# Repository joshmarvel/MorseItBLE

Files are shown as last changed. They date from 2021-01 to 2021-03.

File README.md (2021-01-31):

# MorseItBLE
A simple Bluetooth interface to use a hardware CW key with the Morse-it app with battery charge indication and reset functionality
### Morse-it Bluetooth Low Emissions Hardware Key
Read more over on my site: [M0WYP.com](https://m0wyp.com/2020/05/08/morse-it-ble-hardware-cw-key/)

### New in Version 2
#### For iOS version 14 or greater only
Get [version 1.0](https://github.com/joshmarvel/MorseItBLE/releases/tag/V1.0) for older iOS versions.

Utilizes iOS 14's ability to repeat a key hold and therefore eliminates the need to send the up arrow.  This should solve a great number of timing issues in the previous version.  However, if you find that there are timing errors (this seems to be related to various types of Apple hardware), make adjustments to the delay lines 76 and 88 in MorseItBLE.ino.

#### This project utilizes (at minimum):

1. An iOS device with Bluetooth LE capabilities
2. [Morse-it](https://apps.apple.com/us/app/morse-it/id284942940)
3. [Adafruit Feather 32u4 Bluefruit LE](https://www.adafruit.com/product/2829)
4. And a physical CW key of your choice.
5. Various bits of wire and a micro USB cable
6. Soldering iron and solder, wire strippers and other basic electronics tools.

#### Procedure
1. Update the firmware on Feather
   1. Easiest way is to download [BlueFruit Connect](https://apps.apple.com/us/app/bluefruit-connect/id830125974)
   2. Open the app, find the "Adafruit Bluefruit LE" device and click the "Connect" button
   3. Scroll down the list, find the "Update" menu option and install the latest firmware
2. Download and install the [Arduino IDE](https://www.arduino.cc/en/main/software)
3. Follow the [Adafruit Arduino setup](https://learn.adafruit.com/adafruit-arduino-ide-setup) guide to add the Adafruit boards to the IDE.
4. Connect the board to the computer with a micro USB cable
5. Create new project in the Arduino IDE
6. Copy the 3 files from the project into your new project.
7. Compile the project
8. Upload the project to the board
9. Wire the CW key to the board
   1. GND - Common on the CW key
   2. PIN A0 - Red LED
   3. PIN A1 - Green LED
   4. PIN A2 - Blue LED
   5. PIN A3 - RESET button
   6. PIN A4 - Dah(_) for iambic keys
   7. PIN A5 - Dit(.) for iambic keys or both for straight keys
10. On your iOS device, go to "Settings" -> "Bluetooth" and discover "MorseKey"
11. Open Morse-it, go the "Tap" tab and test sending.

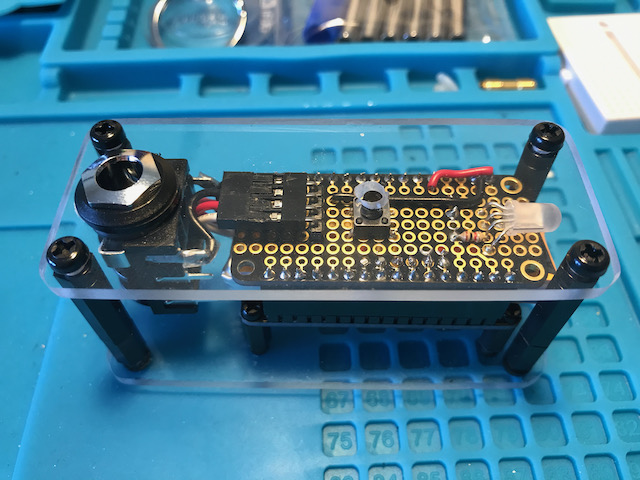
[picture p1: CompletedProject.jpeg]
Completed Project


#### A huge thanks to the work done by Chris Young on his [tutorials](https://learn.adafruit.com/ios-switch-control-using-ble) and [GitHub page](https://github.com/cyborg5/iOS_switch_control/).  This project is adapted and modified from his original work and is licensed under [Creative Commons ShareALike](https://creativecommons.org/licenses/by-nc-sa/4.0/legalcode).

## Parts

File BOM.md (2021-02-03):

# Build of Materials
I've included links to purchase most of the parts at [Adafruit](https://www.adafruit.com/) for ease of purchasing.  Not all parts are as pictured.

| Part | Description | Quantity | Link |
| --- | --- | --- | --- |
| Adafruit Feather 32u4 Bluefruit LE | Main Board | 1 | [Link](https://www.adafruit.com/product/2829) | 
| FeatherWing Proto - Prototyping Add-on For All Feather Boards | Add-on Board | 1 | [Link](https://www.adafruit.com/product/2884) |
| Header Kit for Feather - 12-pin and 16-pin Female Header Set | Headers | 1 | [Link](https://www.adafruit.com/product/2886) |
| Break-away 0.1" 36-pin strip right-angle male header (10 pack) | Headers | 1 | [Link](https://www.adafruit.com/product/1540) | 
| Lithium Ion Polymer Battery Ideal For Feathers - 3.7V 400mAh | Battery | 1 | [Link](https://www.adafruit.com/product/3898) |
| Neutrik NMJ6HCD2 | Switching Jack | 1 | [Link](https://www.neutrik.com/en/product/nmj6hcd2)|
| Diffused RGB (tri-color) LED - Common Anode | LED | 1 | [Link](https://www.adafruit.com/product/159) |
| 4 Pin 2.54mm Dupont Housing | Connector | 1 | [Link](https://www.adafruit.com/product/3145) |
| Female 2.54mm Dupont cable - pre-terminated > 40 mm| Main Board to Jack cable | 4 | [Link](https://www.adafruit.com/product/3141) | 
| 2.0mm JST-PH JST Connector | Power Connector | 1 | [Link](https://www.adafruit.com/product/4422) |
| Through-Hole Resistors - 1.0K ohm 5% 1/4W | Resistor | 1 | [Link](https://www.adafruit.com/product/4294) |
| Tactile Switch Button | Reset Switch | 1 | [Link](https://www.adafruit.com/product/1119) |
| 6 mm Black Nylon Screw - M3 | Case Screws | 8 | [Link](https://www.adafruit.com/product/4685) |
| 30mm Black Nylon Standoff - M3 | Case Standoffs | 4 | [Link](https://www.adafruit.com/product/4685) |
| 6 mm Black Nylon Screw - M2.5 | Main Board Mounting Screws | 8 | [Link](https://www.adafruit.com/product/3299) |
| 10 mm Black Nylon Standoff - M2.5 | Main Board Mounting Standoffs | 4 | [Link](https://www.adafruit.com/product/3299) |
| Misc Multicoloured Silicone Wire | Wire | 1 | [Link](https://www.adafruit.com/product/1970) | 
| 3mm Custom Plexiglass Top Case | Case | 1 | Widely Available |
| 3mm Custom Plexiglass Bottom Case | Case | 1 | Widely Available |

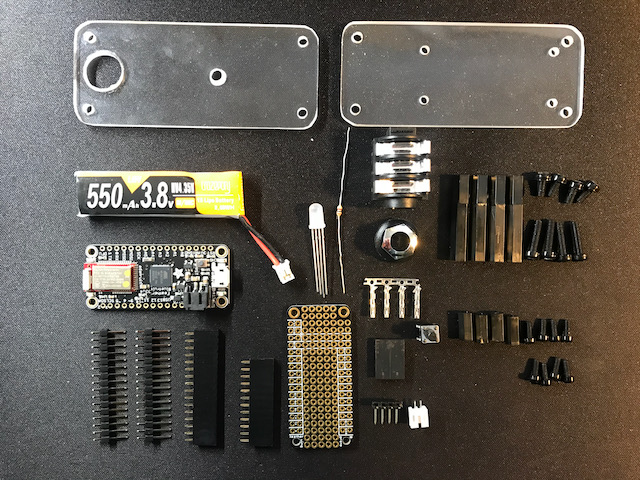
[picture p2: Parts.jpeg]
Part List


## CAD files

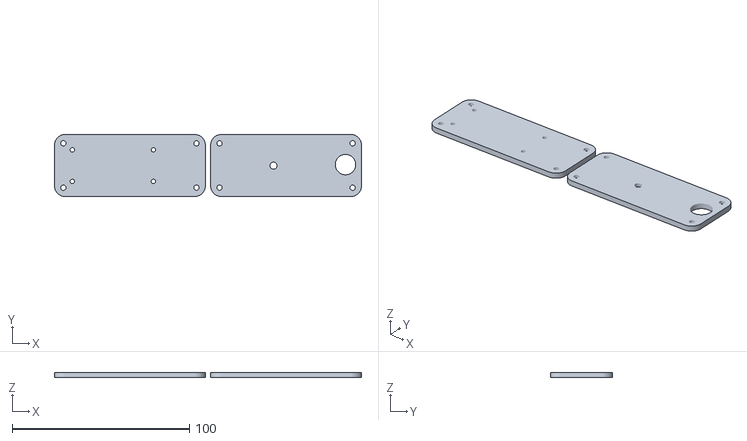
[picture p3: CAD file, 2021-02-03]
MorseItBLE_Case.stl
173.0 x 35.0 x 3.00

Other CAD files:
MorseItBLE_Case.dwg

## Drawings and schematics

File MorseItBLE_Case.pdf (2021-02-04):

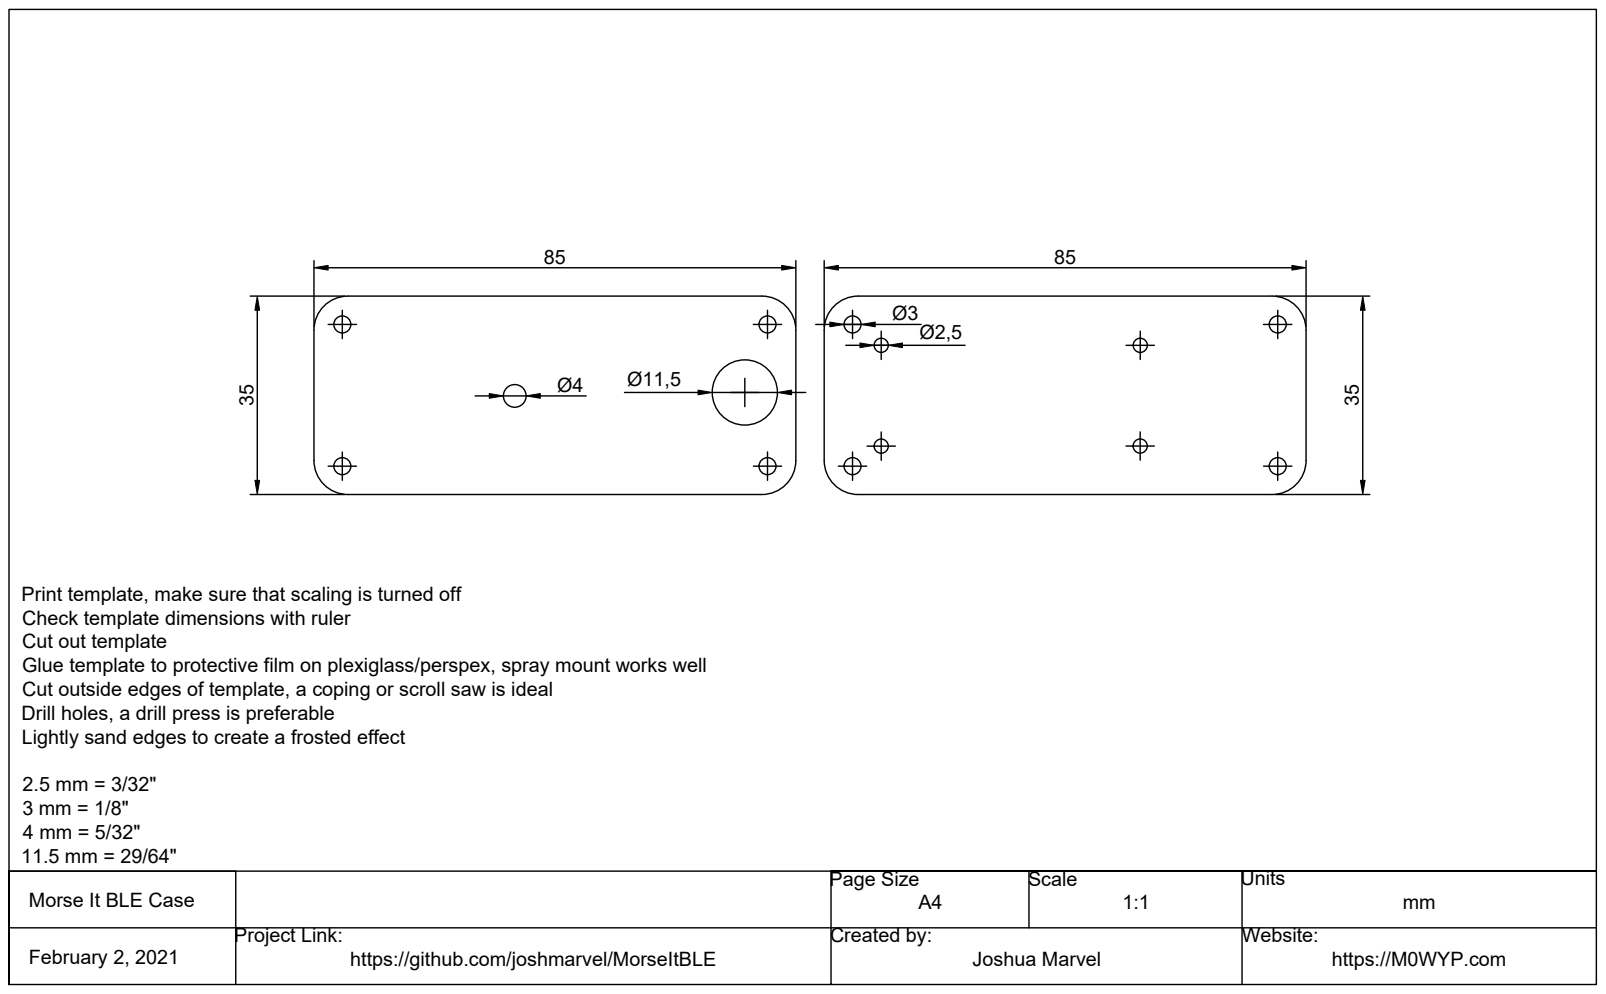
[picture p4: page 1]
Print template,; make sure that scaling is turned off; Glue template to protective film on plexiglass/perspex,; spray mount works well; Cut outside edges of template,; a coping or scroll saw is ideal; Drill holes,; a drill press is preferable

Check template dimensions with ruler

Cut out template

Lightly sand edges to create a frosted effect

Morse It BLE Case | Page Size A4 | Scale 1:1 | Units mm

Project Link: February 2, 2021 https://github.com/joshmarvel/MorseItBLE | Created by: Joshua Marvel | | Website: https://M0WYP. com

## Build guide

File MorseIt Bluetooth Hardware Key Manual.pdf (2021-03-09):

# MorseIt Bluetooth Hardware Key Manual

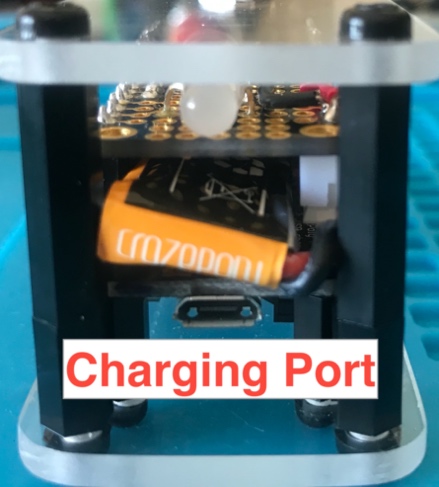
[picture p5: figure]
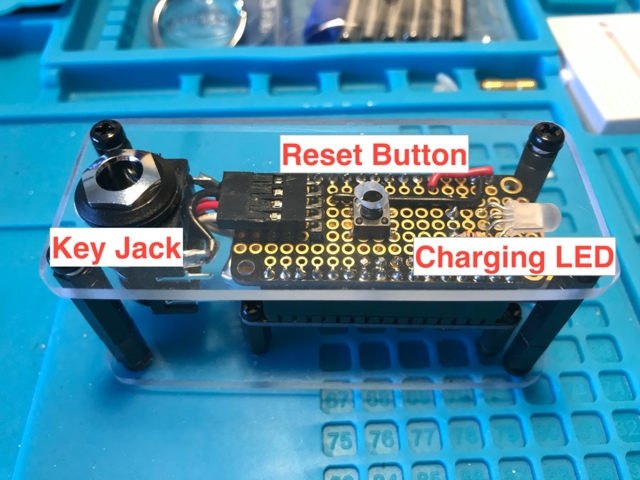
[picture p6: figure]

1. Download and install the MorseIt App from the Apple Store, use the QR Code and your camera app to access it directly. To fully utilize, you’ll need to pay for the app via in app purchases.
2. Plug your key into the unit; it will automatically power the unit on.
3. On your iOS device, go to Settings -> Bluetooth and from the list select the device “MorseKey” from the list and allow it to pair.

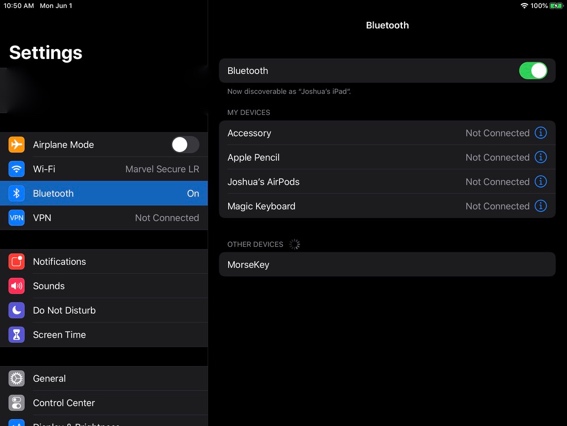
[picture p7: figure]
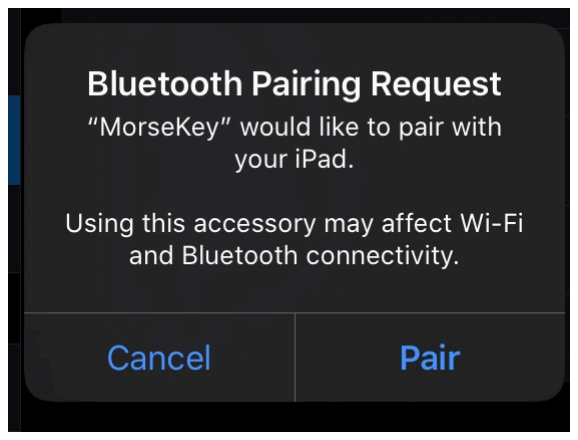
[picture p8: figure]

4. Open the MorseIt App, go to Settings -> Key Type and configure your key.
5. From the bottom menu, select the “Tap” icon and test the key.
6. Make sure to unplug the key when done using to keep the battery from draining.

Charging
When the LED on the jack side of the device changes to red the battery is low.
1. Plug the key (or any plug adapter) into the device.
2. Plug a USB mini cable in the charging port. Battery is full when the LED turns blue.

Reset
1. Press and hold the reset button for 2 seconds, the LED will flash through red, green and blue and then hold solid red.
2. Repeat the pairing process with the iOS device.

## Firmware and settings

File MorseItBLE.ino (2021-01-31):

//Morse-it Bluetooth Hardware Key
//THIS VERSION IS FOR iOS 14 AND NEWER ONLY

//Pin A0 is for RED LED
//Pin A1 is for Green LED
//Pin A2 is for Blue LED
//Pin A3 is for Factory Reset
//Pin A4 is Dah
//Pin A5 is Dit
//All commands sent are the defaults for the Morse-it app

//Set debug to 1 to enable console debug messages.
#define MY_DEBUG 0

#include "BluefruitRoutines.h"

//Battery Monitoring and Indicating
#define RED A0
#define GREEN A1
#define BLUE A2
#define VBAT A9

//Pin for factory reset
#define RESET A3

//Pin numbers for paddles
#define DAH A4
#define DIT A5

//Press and hold pin A2 LOW for 2 seconds to blink LED and forget all previously paired devices and all dynamic memory
void factoryreset(void){
    //MESSAGE(F("Reset Pressed."));
    delay(2000);
    if (digitalRead(RESET) == LOW){
      delay(500);
      analogWrite(BLUE, 0);
      analogWrite(GREEN, 0);
      analogWrite(RED, 255);
      delay(500);
      analogWrite(RED, 0);
      analogWrite(BLUE, 255);
      delay(500);
      analogWrite(BLUE, 0);
      analogWrite(GREEN, 255);
      ble.factoryReset();
      ble.reset();
      analogWrite(RED, 255);
      delay(1000);
      setup();
     }
}

//Setup device and assign pinModes
void setup() {
#if(MY_DEBUG)
  while (! Serial) {}; delay (500);
  Serial.begin(9600); Serial.println("Debug output");
#endif
  pinMode(DAH, INPUT_PULLUP);
  pinMode(DIT, INPUT_PULLUP);
  pinMode(RESET, INPUT_PULLUP);
  pinMode(GREEN, OUTPUT);
  pinMode(RED, OUTPUT);
  pinMode(BLUE, OUTPUT);
  initializeBluefruit();
}

//Defines the characters to be sent.
void loop() {
  while (digitalRead(DIT) == LOW){
    ble.println(F("AT+BLEKEYBOARDCODE=00-00-50-00-00-00-00")); //Send left arrow key
    if (digitalRead(DIT) == LOW && digitalRead(DAH) == LOW){
      ble.println(F("AT+BLEKEYBOARDCODE=00-00-50-00-00-00-00")); //Send left arrow key
      ble.println(F("AT+BLEKEYBOARDCODE=00-00-4F-00-00-00-00")); //Send right arrow key
    }
    delay(10);  //This can be adjusted if you are experiencing issues with doubled characters or stuck characters, value is in milliseconds
    if (digitalRead(DIT) == HIGH && digitalRead(DAH) == HIGH){ //release the key
      ble.println(F("AT+BLEKEYBOARDCODE=00-00"));
      }
    }

  while (digitalRead(DAH) == LOW){
    ble.println(F("AT+BLEKEYBOARDCODE=00-00-4F-00-00-00-00")); //Send right arrow key
     if (digitalRead(DIT) == LOW && digitalRead(DAH) == LOW){
      ble.println(F("AT+BLEKEYBOARDCODE=00-00-4F-00-00-00-00")); //Send right arrow key
      ble.println(F("AT+BLEKEYBOARDCODE=00-00-50-00-00-00-00")); //Send left arrow key
    }
    delay(10);  //This can be adjusted if you are experiencing issues with doubled characters or stuck characters, value is in milliseconds
    if (digitalRead(DIT) == HIGH && digitalRead(DAH) == HIGH){ //release the key
      ble.println(F("AT+BLEKEYBOARDCODE=00-00"));
      }
    }

  if (digitalRead(RESET) == LOW){ //Monitors for reset button push
    factoryreset();
    }

   //Battery Voltage Monitoring, Blue LED for external USB power/Full Charge, Green for Normal power, Red for charge needed.
  float bvolt = analogRead(VBAT);
  bvolt *= 2;
  bvolt *= 3.3;
  bvolt /= 1024;
  if (bvolt > 4.1){
    analogWrite(BLUE, 255);
    analogWrite(RED, 0);
    analogWrite(GREEN, 0);
  }
  else if (bvolt <= 4.1 && bvolt >= 3.7) {
    analogWrite(GREEN, 255);
    analogWrite(BLUE, 0);
    analogWrite(RED, 0);
  }
  else if (bvolt < 3.7){
    analogWrite(RED, 255);
    analogWrite(GREEN, 0);
    analogWrite(BLUE, 0);
  }
  //MESSAGE(bvolt);
}

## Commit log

2020-05-10 Fix for Iambic keying alternation
    Built logic for Iambic keying to properly insert characters.
    [MorseItBLE.ino]
2020-05-12 Added comments and battery voltage monitoring via an LED.
2020-05-12 Move battery monitoring to the main loop for constant monitoring.
2020-05-21 Add factory reset button, moved pins around to make it easier to layout a feather proto board.
2021-01-31 Occasional Stuck Key Issue Resolved
    Fixed issue with an occasional stuck key by using while loops instead of if loops.
    [MorseItBLE.ino]
2021-01-31 Project BOM and Case Photos
    Add a parts list and a couple photos.
2021-01-31 Add pictures to README & BOM
2021-02-03 Adding Case Drawings
    [MorseItBLE_Case.dwg, MorseItBLE_Case.stl]
2021-02-04 Eliminate unnecessary holes in drawings
    [MorseItBLE_Case.dwg]
